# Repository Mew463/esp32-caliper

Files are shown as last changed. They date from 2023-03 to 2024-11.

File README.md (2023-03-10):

# Summary
This project adds bluetooth functionality to an ordinary set of calipers with an embedded ESP32 C3. It's main purpose was to speed up CAD Development with it's ability to automatically enter numbers into OnShape.


It features a built in 150mAh battery and a USB C interface for charging/uploading code. 

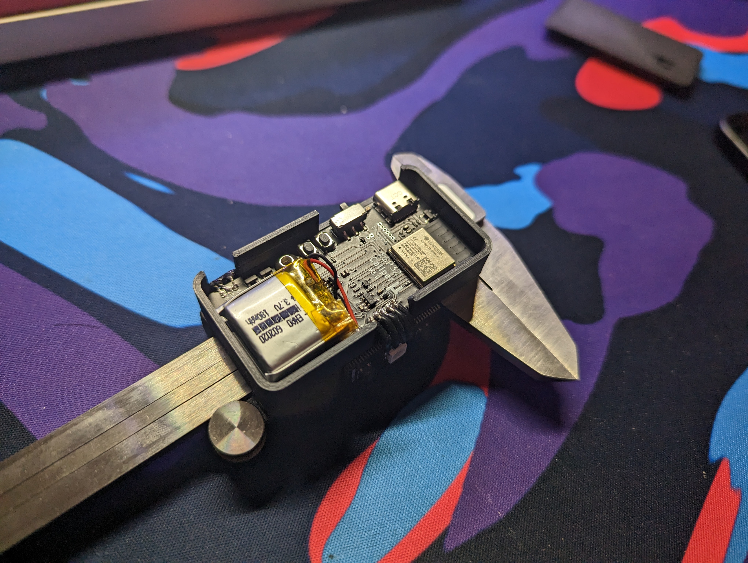
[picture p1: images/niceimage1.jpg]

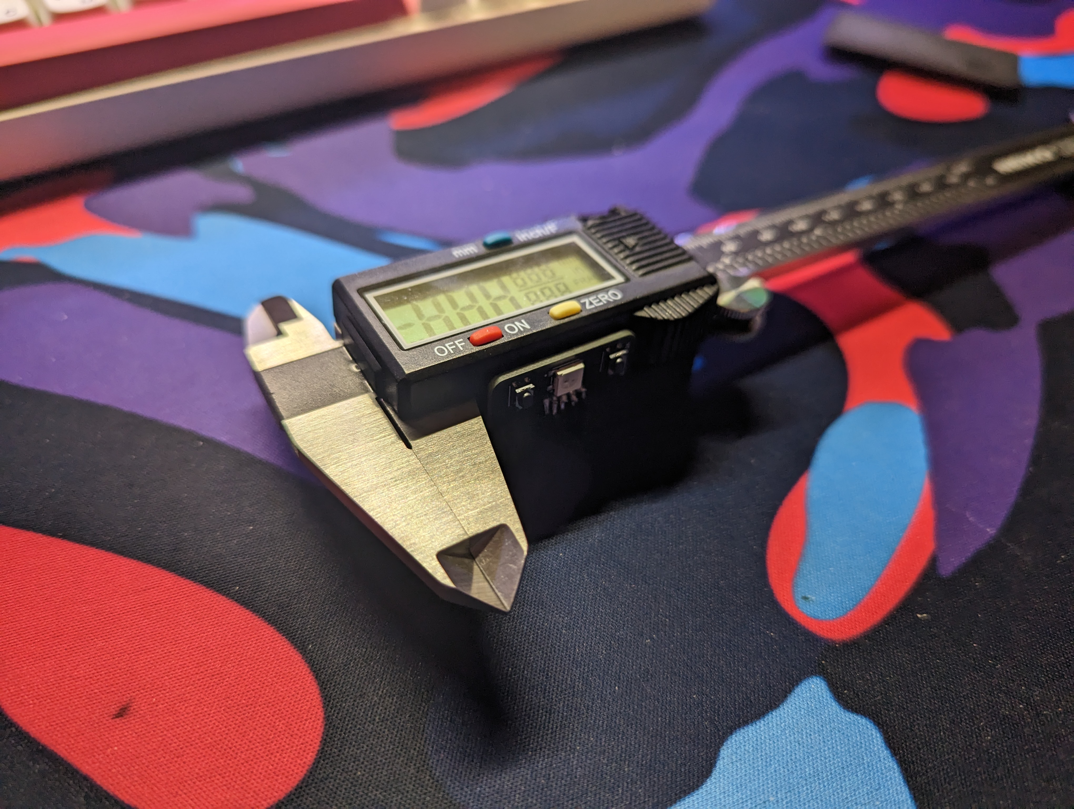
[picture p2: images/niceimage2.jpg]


This is meant to be a direct replacement for the GROSS solution that you could just buy for the inexpensive price of $100:
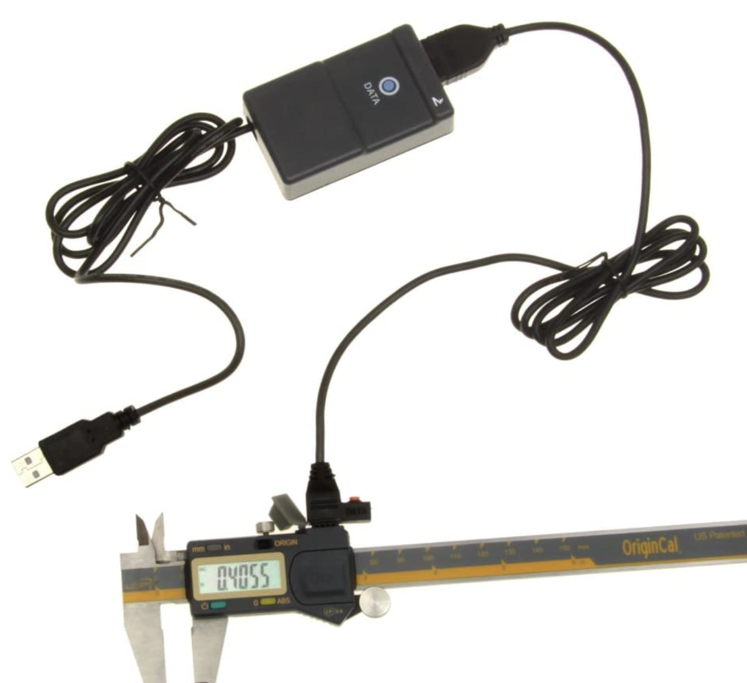
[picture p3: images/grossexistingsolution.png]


# Features
- Realtime battery reporting
- Two User buttons 
    - Button1 enters numbers and then presses Enter
    - Button2 enters numbers and then inserts a space so that the user can add tolerance
- Neopixel indicator (States: Bluetooth pairing, Connected, Button 1 or 2 Pressed, Entering deep sleep)
- 20 day standby time or 2hr usage time 
- Charge light
- Snap-on PCB Case

# Decoding the Caliper Data
[Calipers Used](https://www.amazon.com/Neiko-01407A-Electronic-Digital-Stainless/dp/B000GSLKIW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)

## Soldering Wires
My old caliper's data output port looked like this:
 
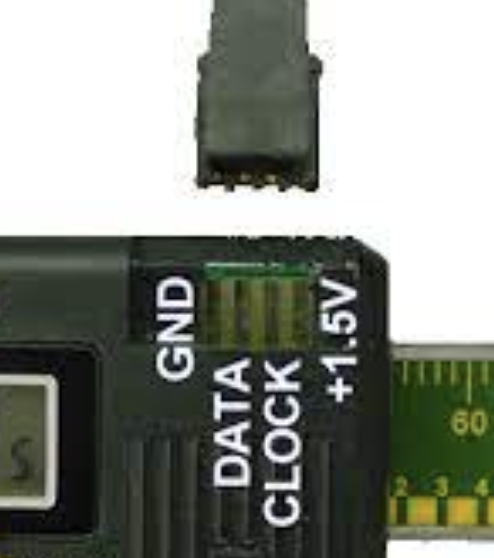
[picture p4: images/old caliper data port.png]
 

Unfortunately I broke the old caliper during this project and had to buy a brand new version of my old caliper. Sometime in the span of 3 years, it seemed that the data output port changed to be adapted for a female micro usb (though there wasn't one soldered on the caliper's pcb).

The smaller pads made it more painful to solder wires to, but it was doable.

With an oscilloscope, I probed each pad to determine which was the clock, data, and ground line.

## Logic converter
Because the Caliper's logic level is 1.5v but the ESP32 is 3v3, I needed to use a logic converter. V1 and V3 use the transistor circuit below which shifts and inverts the clock and data lines coming from the caliper. V2 used a IC level shifter which didn't work at all for some unknown reason. 

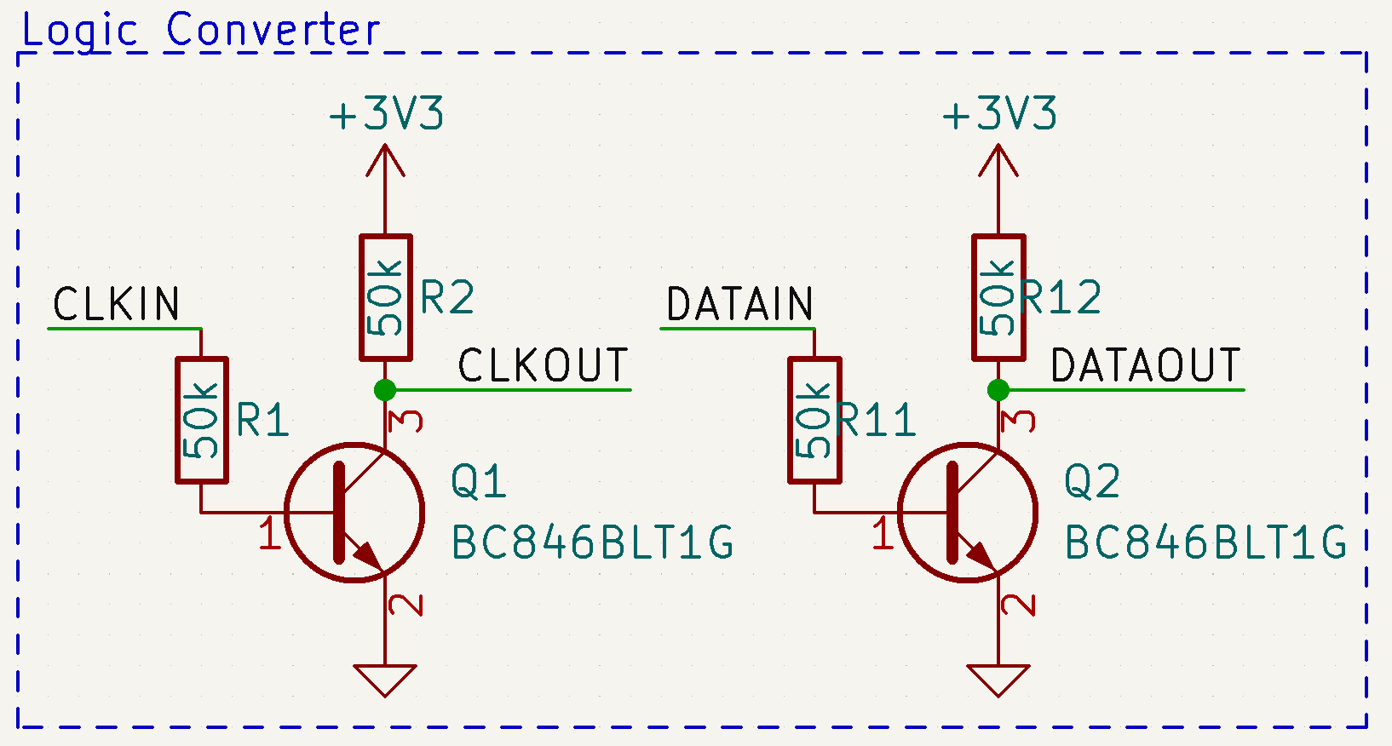
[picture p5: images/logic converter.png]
 Logic converter

## Data protocol
Like many other people who have decoded their caliper, I discovered that there are 24 bits sent out by the caliper:

The bit at index[0] is always 1.

Bits from index[1] - index[15] signify the value with the LCB being first.

Index[21] signifies a negative number.

My old caliper had one bit to indicate the unit, but my new caliper did not have this bit (? idk why).

# Creation
## KiCAD
Designed in KiCAD 6.0. Bought from Mouser and manufactured by JLCPCB. I assembled them by hand.

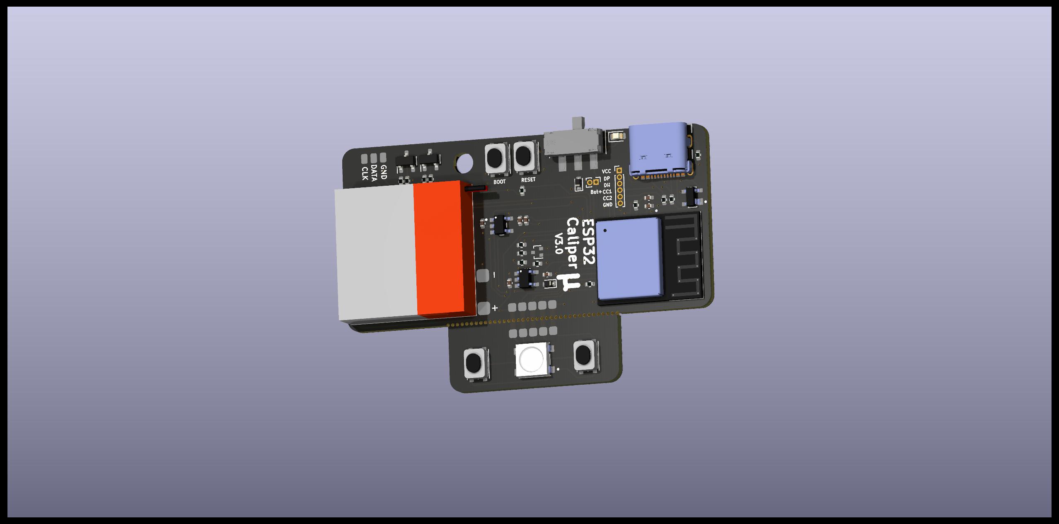
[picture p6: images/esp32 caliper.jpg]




## CAD
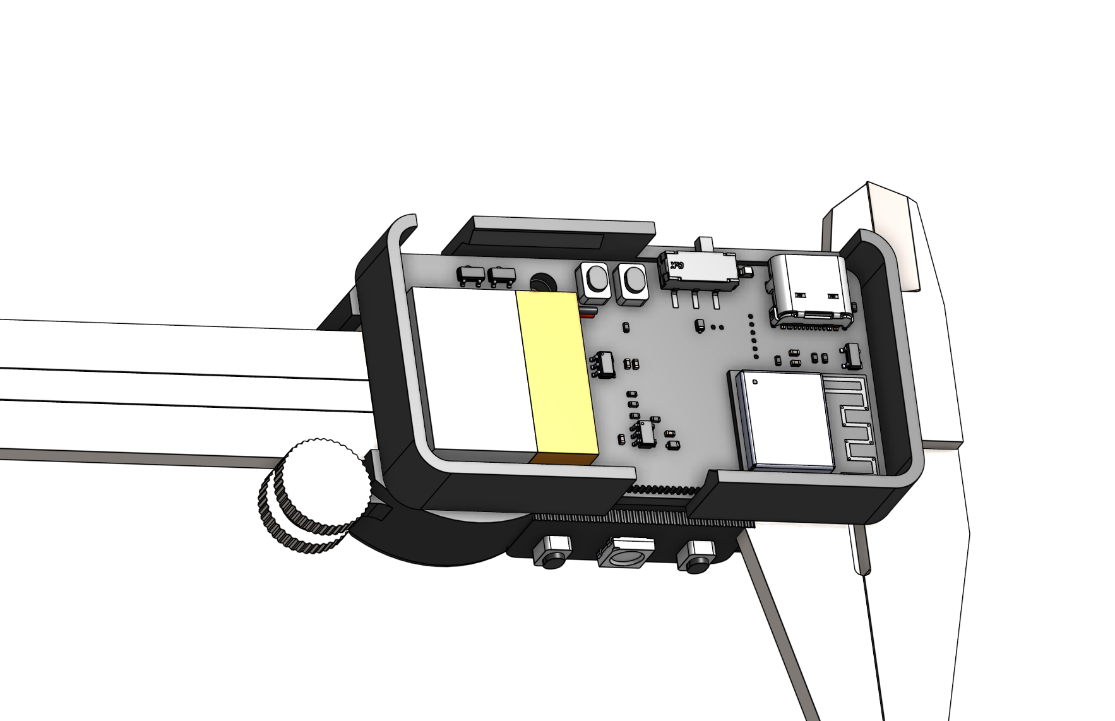
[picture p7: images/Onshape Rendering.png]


[CAD](https://cad.onshape.com/documents/368abd500c875635f19a3005/w/ab7db60efad03bd7d6054350/e/1cf117eaa5e9ddddb41ff0d8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)

# Summary 
This project took like 40 hours and 3 revisions of pcbs.
If you really want a bluetooth caliper just buy one premade, it'll save you a lot of headache. Otherwise this is a fun intro-to-embedded project.

[Premade bluetooth calipers](https://www.amazon.com/iGaging-Electronic-Absolute-Bluetooth-Connectivity/dp/B0716B8Q99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)

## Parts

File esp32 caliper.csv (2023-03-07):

Quantity | Manufacturer
1 | ASR00003
2 | GRM155R60J475ME87D
3 | GCM155C71A105KE38D
1 | GRM155R60J106ME15D
1 | GRM152R61A104KE19D
1 | SP0503BAHTG
1 | 485-1655
2 | NSR05T30XV2T5G
1 | LTST-S270KRKT
1 | GCT
1 | SSM3K36FS,LF
5 | ERJ-2RKF4992X
4 | ERJ-2RKF5101X
1 | ERA-2VEB1003X
1 | ERJ-H2RD2001X
1 | ERJ-H2RD4700X
2 | ERJ-2RKF1002X
1 | JS102011SAQN
1 | 434133025816
1 | 434133025816
1 | 434133025816
1 | 434133025816
1 | MCP73831T-5ACI/OT
1 | LP5907MFX-3.3/NOPB
1 | ESP32-C3-MINI-1-N4

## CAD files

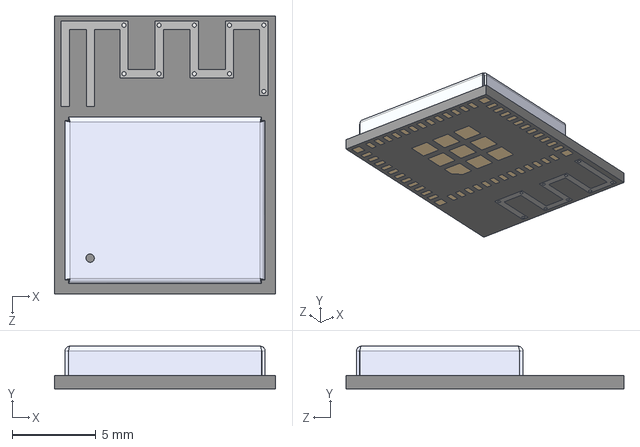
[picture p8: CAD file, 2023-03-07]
ESP32-C3-MINI-1-N4/ESP32-C3-MINI-1-N4.step
13.2 x 2.55 x 16.6 mm

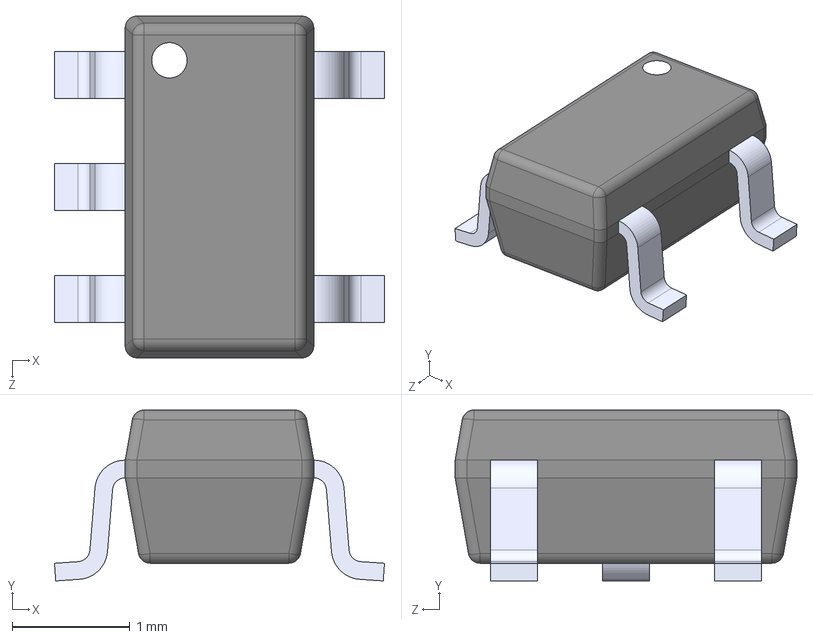
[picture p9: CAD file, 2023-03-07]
LP5907MFX-3.3_NOPB/LP5907MFX-3.3_NOPB.step
2.80 x 1.45 x 2.90 mm

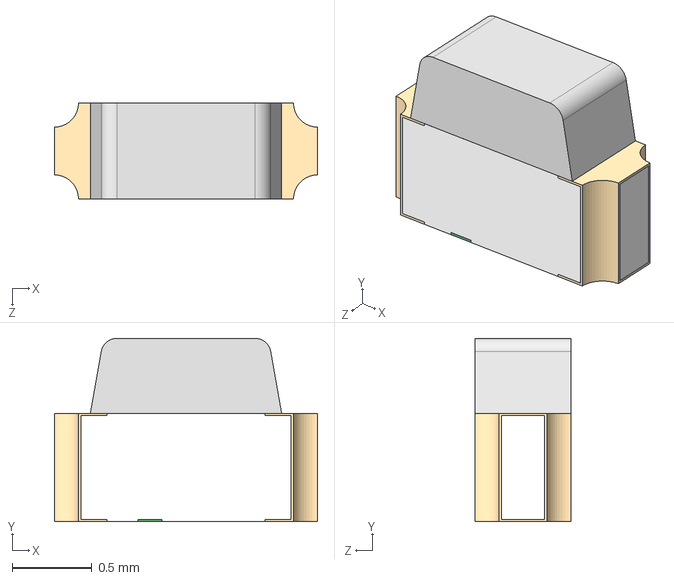
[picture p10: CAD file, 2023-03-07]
LTST-S270KRKT/LTST-S270KRKT.step
1.65 x 1.15 x 0.6 mm

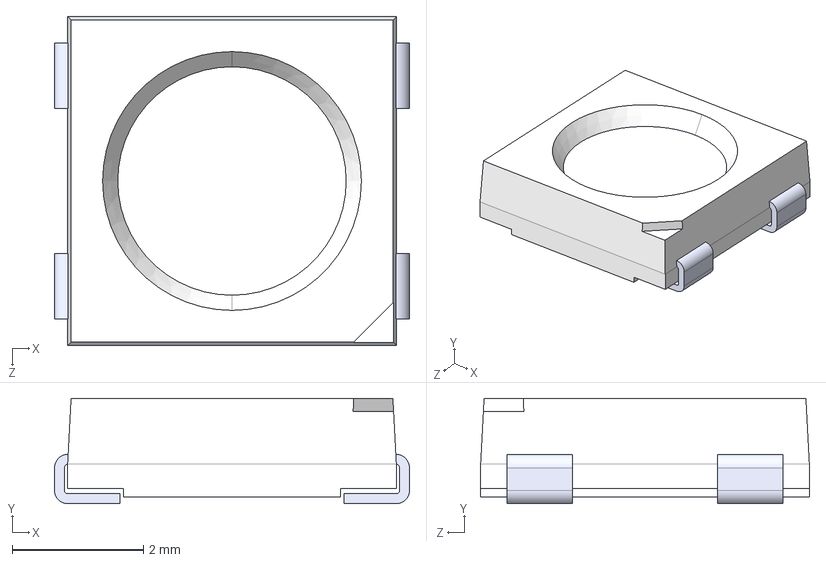
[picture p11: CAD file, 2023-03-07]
NeoPixel/1655--3DModel-STEP-56544.STEP
5.40 x 1.60 x 5.00 mm

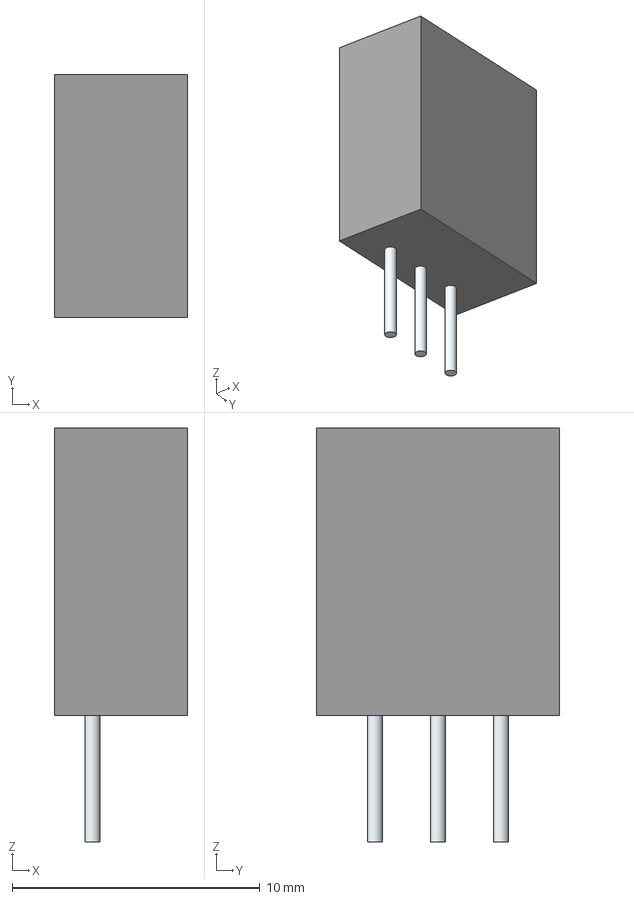
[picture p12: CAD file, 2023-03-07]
slide switch/AS11AP.stp
5.38 x 9.80 x 16.7 mm
Leads

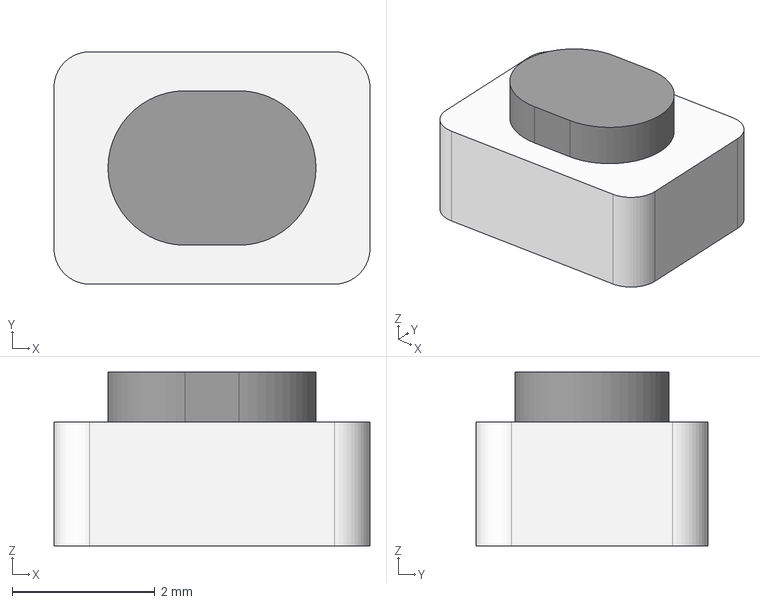
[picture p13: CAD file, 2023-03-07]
SMD Button.step
4.42 x 3.25 x 2.43 mm

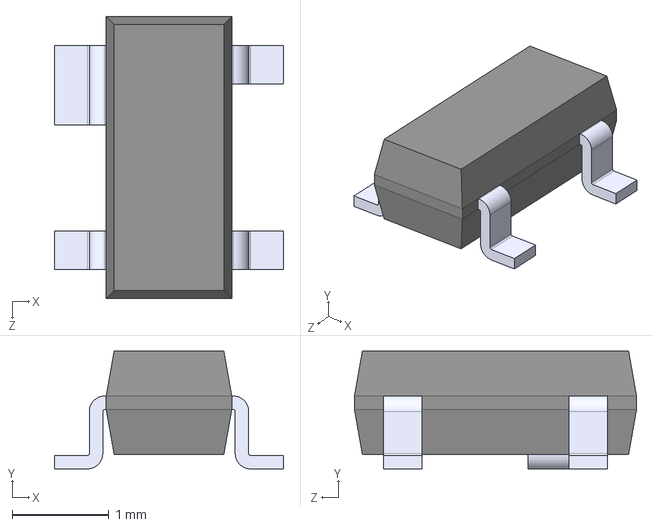
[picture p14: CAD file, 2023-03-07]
SP0503BAHTG/SP0503BAHTG.step
2.37 x 1.22 x 2.92 mm

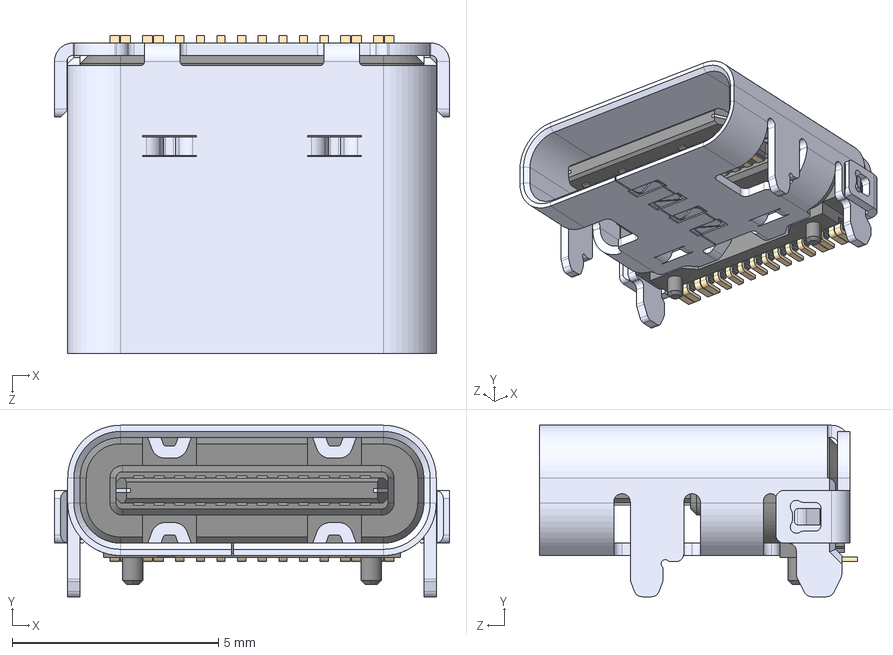
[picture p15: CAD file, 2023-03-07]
USB4105-GF-A/USB4105-GF-A.step
9.58 x 4.16 x 7.71 mm

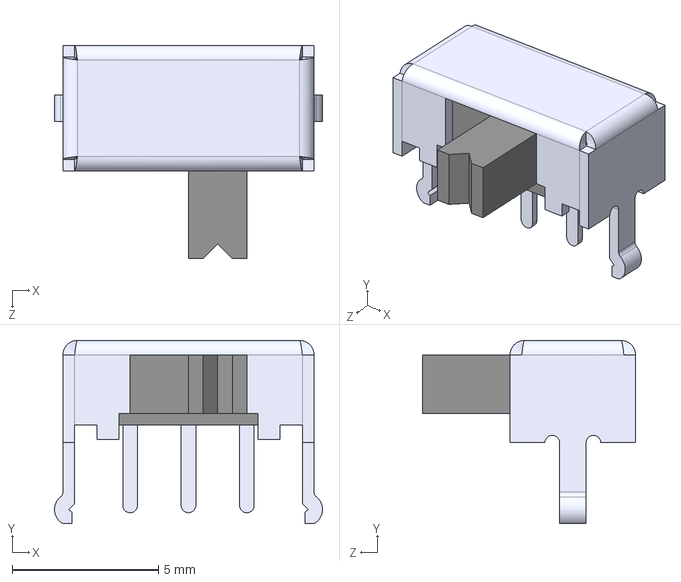
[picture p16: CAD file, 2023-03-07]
1825232-1/1825232-1.step
9.17 x 6.27 x 7.30 mm

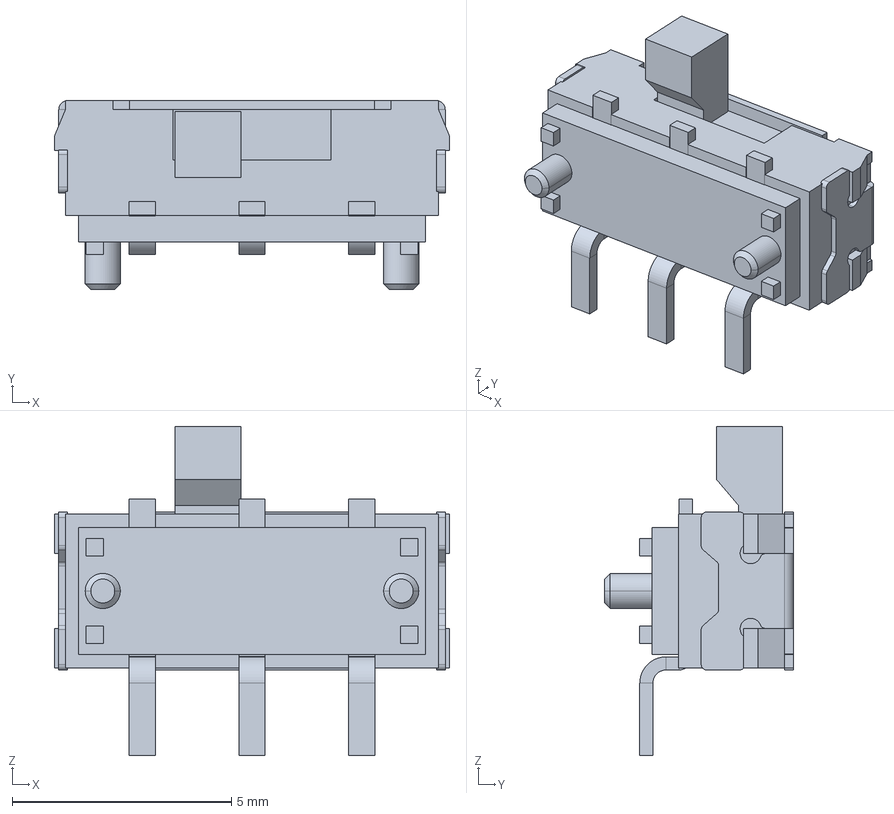
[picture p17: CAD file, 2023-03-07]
JS102011SAQN/JS102011SAQN.step
9.00 x 4.30 x 7.50 mm

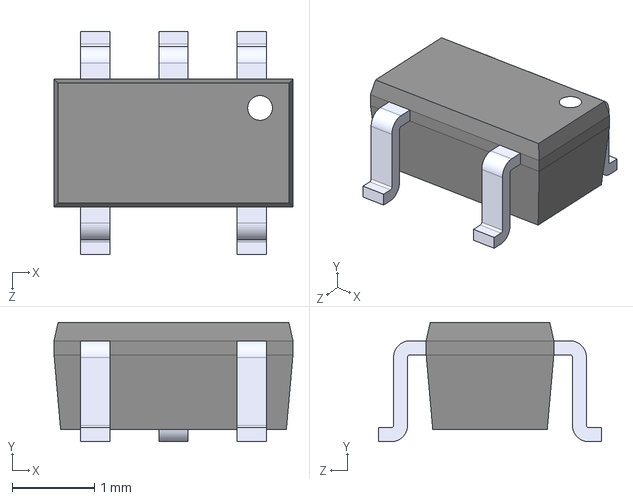
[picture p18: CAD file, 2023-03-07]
MCP73831T-5ACI_OT/MCP73831T-5ACI_OT.step
2.90 x 1.45 x 2.70 mm

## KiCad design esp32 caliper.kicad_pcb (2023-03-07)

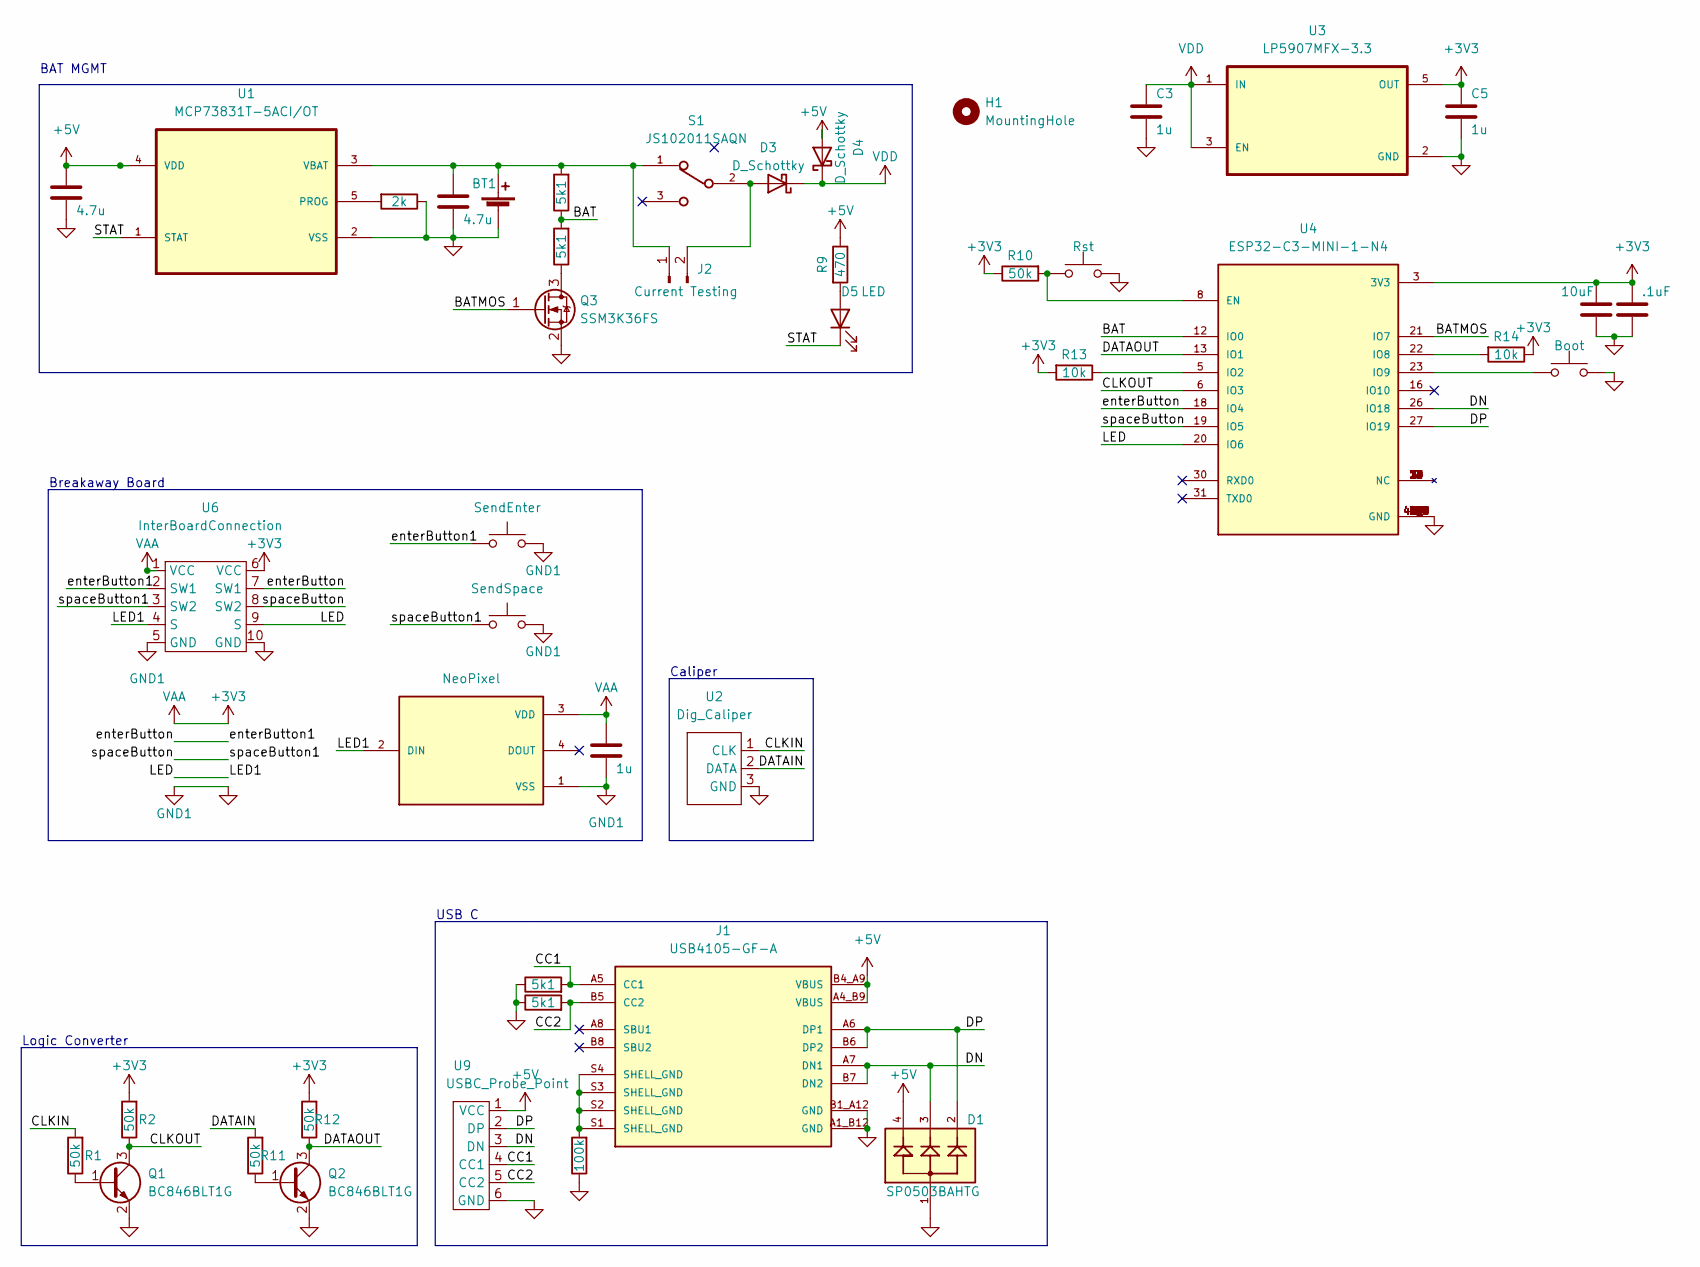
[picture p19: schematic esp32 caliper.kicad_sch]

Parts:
BT1: 3.7; Battery
C1, C2: 4.7u; C_0402_1005Metric
C3, C4, C5: 1u; C_0402_1005Metric
C9: 10uF; C_0402_1005Metric
C10: .1uF; C_0402_1005Metric
D1: SP0503BAHTG; SOT143; PARTREV N/A
D2: NeoPixel; LED_1655; PARTREV 01
D3, D4: D_Schottky; D_SOD-523
D5: LED; LED_0603_1608Metric
H1: MountingHole; MountingHole_3.2mm_M3
J1: USB4105-GF-A; GCT_USB4105-GF-A; PARTREV A3
J2: Current Testing; PinHeader_1x02_P1.00mm_Vertical
Q1, Q2: BC846BLT1G; SOT-23
Q3: SSM3K36FS; SOT-416
R1, R2, R10, R11, R12: 50k; R_0402_1005Metric
R3, R4, R5, R7: 5k1; R_0402_1005Metric
R6: 100k; R_0402_1005Metric
R8: 2k; R_0402_1005Metric
R9: 470; R_0402_1005Metric
R13, R14: 10k; R_0402_1005Metric
S1: JS102011SAQN; SW_JS102011SAQN
SW1: Boot; SW_Push_1P1T_NO_Vertical_Wuerth_434133025816
SW2: Rst; SW_Push_1P1T_NO_Vertical_Wuerth_434133025816
SW3: SendEnter; SW_Push_1P1T_NO_Vertical_Wuerth_434133025816
SW4: SendSpace; SW_Push_1P1T_NO_Vertical_Wuerth_434133025816
U1: MCP73831T-5ACI/OT; SOT95P280X145-5N; MPN MCP73831T-5ACI/OT
U2: Dig_Caliper; Caliper
U3: LP5907MFX-3.3; SOT95P280X145-5N
U4: ESP32-C3-MINI-1-N4; XCVR_ESP32-C3-MINI-1-N4; PARTREV v1.0
U6: InterBoardConnection
U9: USBC_Probe_Point; PinHeader_1x06_P1.00mm_Vertical

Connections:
+3V3: C4.1, C5.1, C9.1, C10.1, D2.3 (VDD), R2.2, R10.1, R12.2, R13.2, R14.1, U3.5 (OUT), U4.3 (3V3), U6.1 (VCC), U6.6 (VCC)
+5V: C1.1, D1.4, D4.2 (A), J1.A4_B9 (VBUS), J1.B4_A9 (VBUS), R9.1, U1.4 (VDD), U9.1 (VCC)
/BAT: R3.1, R7.2, U4.12 (IO0)
/BATMOS: Q3.1 (G), U4.21 (IO7)
/CC1: J1.A5 (CC1), R4.2, U9.4 (CC1)
/CC2: J1.B5 (CC2), R5.2, U9.5 (CC2)
/CLKIN: R1.2, U2.1 (CLK)
/CLKOUT: Q1.3 (C), R2.1, U4.6 (IO3)
/DATAIN: R11.2, U2.2 (DATA)
/DATAOUT: Q2.3 (C), R12.1, U4.13 (IO1)
/DN: D1.3, J1.A7 (DN1), J1.B7 (DN2), U4.26 (IO18), U9.3 (DN)
/DP: D1.2, J1.A6 (DP1), J1.B6 (DP2), U4.27 (IO19), U9.2 (DP)
/LED: D2.2 (DIN), U4.20 (IO6), U6.4 (S), U6.9 (S)
/STAT: D5.1 (K), U1.1 (STAT)
/enterButton: SW3.1, U4.18 (IO4), U6.2 (SW1), U6.7 (SW1)
/spaceButton: SW4.1, U4.19 (IO5), U6.3 (SW2), U6.8 (SW2)
GND: BT1.2 (-), C1.2, C2.2, C3.2, C4.2, C5.2, C9.2, C10.2, D1.1, D2.1 (VSS), J1.A1_B12 (GND), J1.B1_A12 (GND), Q1.2 (E), Q2.2 (E), Q3.2 (S), R4.1, R5.1, R6.1, R8.1, SW1.2, SW2.1, SW3.2, SW4.2, U1.2 (VSS), U2.3 (GND), U3.2 (GND), U4.1 (GND), U4.2 (GND), U4.11 (GND), U4.14 (GND), U4.36 (GND), U4.37 (GND), U4.38 (GND), U4.39 (GND), U4.40 (GND), U4.41 (GND), U4.42 (GND), U4.43 (GND), U4.44 (GND), U4.45 (GND), U4.46 (GND), U4.47 (GND), U4.48 (GND), U4.49_1 (GND), U4.49_2 (GND), U4.49_3 (GND), U4.49_4 (GND), U4.49_5 (GND), U4.49_6 (GND), U4.49_7 (GND), U4.49_8 (GND), U4.49_9 (GND), U4.50 (GND), U4.51 (GND), U4.52 (GND), U4.53 (GND), U6.5 (GND), U6.10 (GND), U9.6 (GND)
unnamed: BT1.1 (+), C2.1, J2.1, R3.2, S1.1, U1.3 (VBAT)
unnamed: D3.2 (A), J2.2, S1.2
unnamed: D5.2 (A), R9.2
unnamed: J1.S1 (SHELL_GND), J1.S2 (SHELL_GND), J1.S3 (SHELL_GND), J1.S4 (SHELL_GND), R6.2
unnamed: Q1.1 (B), R1.1
unnamed: Q2.1 (B), R11.1
unnamed: Q3.3 (D), R7.1
unnamed: R8.2, U1.5 (PROG)
unnamed: R10.2, SW2.2, U4.8 (EN)
unnamed: R13.1, U4.5 (IO2)
unnamed: R14.2, U4.22 (IO8)
unnamed: SW1.1, U4.23 (IO9)
VDD: C3.1, D3.1 (K), D4.1 (K), U3.1 (IN), U3.3 (EN)

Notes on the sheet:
Breakaway Board
USB C
Logic Converter
Caliper
BAT MGMT

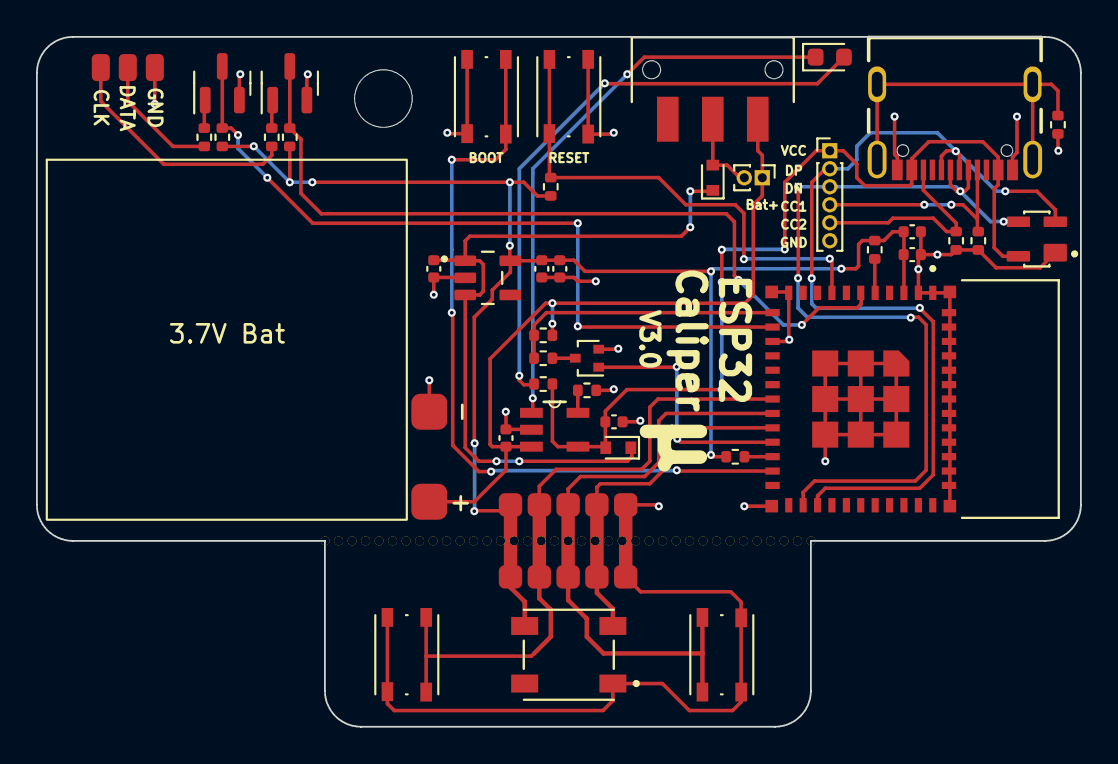
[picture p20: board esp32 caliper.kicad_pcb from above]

Board: 2 copper layers, 58.0 x 38.3 mm, 44 parts (0 on the bottom side), 30 nets.

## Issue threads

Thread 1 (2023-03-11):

Power Caliper from Li-Ion battery?

ccoenen, 2023-03-11:
This is a great project! I came here because it was featured on Hackaday just now.

I wonder if one could add another regulator to output 1.5V so that we could get rid of the coin cell of this thing? Did you try to power the calipers from that fourth pin?

DaVarga, 2023-03-13:
I just added a 1.5V regulator.
#2

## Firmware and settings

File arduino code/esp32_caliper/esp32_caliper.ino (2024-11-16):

#include <USB.h>
#include <BleKeyboard.h>
#include <Adafruit_NeoPixel.h>
#include "/Users/mingweiyeoh/Documents/GitHub/Arduino-Projects/libraries/Custom/MyButton.h"

#define LED_PIN 6

Adafruit_NeoPixel pixels(1, LED_PIN, NEO_GRB + NEO_KHZ800);

// Pin definitions
int batPin = 0;
int dataIn = 1;
int clockIn = 3;
MyButton enterEntry = MyButton(4);
MyButton regEntry = MyButton(5);
int batMos = 7;

// Caliper settings
bool inInches = 0;

// Battery stuff
float timeOutMins = 3;
unsigned long lastBatUpdate = millis();
unsigned long lastDataSend = millis();

BleKeyboard bleKeyboard("ESP32 Caliper", "", 100);

void setup() {
  pinMode(dataIn, INPUT);
  pinMode(clockIn, INPUT);
  pinMode(batMos, OUTPUT);

  USBSerial.begin(115200);

  pixels.begin();

  if (enterEntry.updateButton() && regEntry.updateButton() ){
    inInches = 1;
    for (int i = 0; i < 3; i++) {
      setColor(221,160,221);
      delay(250);
      setColor(0,0,0);
      delay(250);
    } 
  }
  

  setColor(0, 0, 255);
  bleKeyboard.begin(); 

  for (int i = 0; i < 10; i++)
    batAvg();

}
void loop() {
  if (millis() - lastDataSend > 1000 * 60 * timeOutMins) {
    enterDeepSleep();
  }

  if (bleKeyboard.isConnected()) {
    if (millis() - lastBatUpdate > 1000) {
      lastBatUpdate = millis();
      bleKeyboard.setBatteryLevel(getBatPerc());
    }
      
    if (regEntry.getInitialPress()) { // Space at the end
      while (!getData()) ;
      sendData(1);
    } 

    if (enterEntry.getInitialPress()) {  // Press enter at the end
      while (!getData()) ;
      sendData(0);
    }
  } else {

    USBSerial.println("No device connected");

    setColor(0,0,255);
    delay(250);
    setColor(0,0,0);
    delay(250);
  }
}

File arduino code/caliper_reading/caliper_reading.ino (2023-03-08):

#include <USB.h>
int dataIn = 1;
int clockIn = 3;

// Variables
int curClock = 1;
int lastClock = 1;
unsigned long timeStart = 0;
int out = 0;
// 
bool data[24] = {0};
int curIndex = 0;
double measurement = 0;

bool inInches = 0;

void setup() {
  // Pi  Set Up
  pinMode(dataIn, INPUT);     
  pinMode(clockIn, INPUT);

  USBSerial.begin(115200);
  delay(500);
  USBSerial.println("Ready!");
}


void loop(){
  if (curIndex == 23) {
    measurement = 0;
    int placeholder;
      if (inInches) {// Inches
        for (int a = 1; a < 15; a++) {
          if (data[a]) 
            placeholder = 1;
          else
            placeholder = 0;

          measurement += placeholder * pow(2, a-1);
        }
        measurement = (measurement * .0005);
        if (data[21])
          measurement *= -1;
        USBSerial.println(measurement, 4);
      }
      else {
        for (int a = 1; a < 15; a++) { // Millimeters
          if (data[a]) 
            placeholder = 1;
          else
            placeholder = 0;

          measurement += placeholder * pow(2, a-1);
        }
        
        measurement = measurement / 100;
        if (data[21])
          measurement *= -1;
        USBSerial.println(measurement,2);
      }
      
      
      // for (int i = 0; i < 24; i++) {
      //   if (i % 4 == 0)
      //     USBSerial.print(" "); 
      //   USBSerial.print(data[i]);
      // }
      // USBSerial.println();

      delay(50); // Makes it more readeable
  }

  lastClock = curClock;
  curClock = digitalRead(clockIn);
  if (lastClock == 0 && curClock == 1){
    
    if((micros() - timeStart) > 3000) // If have not received data in the last 700 us then reset
    {    
      // Serial.println("");
      curIndex = 0;
    }
    else if((micros() - timeStart) > 400 && curIndex != 1){
      // Serial.print(" ");
    }
    out = digitalRead(dataIn)+digitalRead(dataIn)+digitalRead(dataIn); // Tripple sampling to remove glitches
    if (out > 1){
      data[curIndex] = 0;
      // Serial.print("0");
    }
    else{
      data[curIndex] = 1;
      // Serial.print("1");
    }
    curIndex++;
    timeStart = micros();
    // Serial.println(curIndex);
  }
}

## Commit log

2023-03-07 Create esp32 caliper.jpg
2023-03-08 fixed random spelling error and uploaded arduino code
    [BatMngmt.ino, Caliper.ino, caliper_reading.ino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]
